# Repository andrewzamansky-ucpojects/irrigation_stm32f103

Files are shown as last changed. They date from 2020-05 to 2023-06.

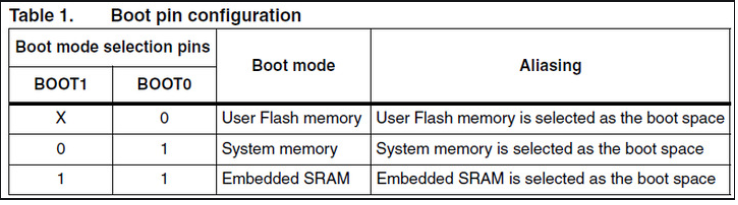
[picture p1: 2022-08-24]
BOOT0_BOOT1_configuration.png

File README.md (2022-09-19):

adc sample of stm32f10x

for using semihost with jlink read "common_public/c/hw_drivers/arch/ARM/semihosting/connect_jlink_with_semihosting.txt"

Debugging:
uncomment following line in main.c(in measurements_thread_func())
before entering hibernation:
//while(1){os_delay_ms(1000);} // to remove, for dbg only

to start JLINK:
for SW thar runs from flash: set BOOT0 and BOOT1 to 1
"C:\Program Files (x86)\SEGGER\JLink\JLink.exe" -device STM32F103C8 -if SWD -speed 4000

to connect to CPU in JLINK cmd line run:
connect

some times board needs to be reset(button) few times before it can connect.

to connect jlink gdb server run:
"C:\Program Files (x86)\SEGGER\JLink\JLinkgdbserver.exe" -device STM32F103C8 -if SWD -speed 4000

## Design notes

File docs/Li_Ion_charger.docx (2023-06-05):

For Li-Ion charger TP4056 chip is used.

To allow simultaneous charging and loading pMOSFET and Schottky Diode are used.

The base of solution was taken from https://www.best-microcontroller-projects.com/tp4056-page2.html

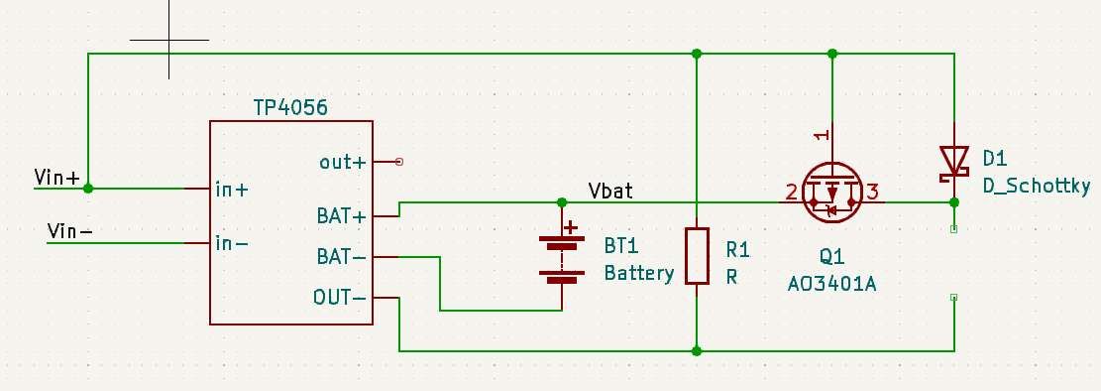
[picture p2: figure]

Vg = Vin

If Vin > 4V then tp4056 will work and charge BT1 battery. Battery charge is from 2.7V to 4.2V so

So Vgs = Vg-(Vb - 0.4V) is more than 0.2V (for highest 4.2V of battery). So Q1 is off. So load is powered by Vin.

If Vin < 4V then tp4056 is not charging the battery. But only when Vgs will be less then -0.55V(typically) then

Q1 will turn on and battery will power the load. So typically Vb-Vg will be > 0.15V.

Note 1: some times on charger board 03962A both red(charging) and blue(standby) LEDs are ‘on’. (while it’s expected that only one of them is ‘on’). I assume that it’s because of high wire resistance the voltage on battery is less than 4.2V, so battery is not fully charge, so when tp4056 stops charging, I is dropped, so IR(voltage) on wires drops, so

More voltage falls on battery so it can pull more current for charging. So tp4056 start charging again. But then it returns to previous condition with higher IR on wires. So it’s toggling between these 2 states causing 2 LEDs to blink very fast, and it looks like they are always ‘on’.

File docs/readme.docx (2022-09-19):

adc sample of stm32f10x

for using semihost with jlink read "common_public/c/hw_drivers/arch/ARM/semihosting/connect_jlink_with_semihosting.txt"

Debugging:

uncomment following line in main.c(in measurements_thread_func())

before entering hibernation:

//while(1){os_delay_ms(1000);} // to remove, for dbg only

1. debugging with J-link

! Cloned J-link are not stable, disconnect after 5-10sec. Better to use Mini Edu official J-link!

to test JLINK:

for SW thar runs from flash: set BOOT0 and BOOT1 to 1

"C:\Program Files (x86)\SEGGER\JLink\JLink.exe" -device STM32F103C8 -if SWD -speed 4000

to connect to CPU in JLINK cmd line run:

connect

some times board needs to be reset(button) few times before it can connect.

to connect jlink gdb server run:

"C:\Program Files (x86)\SEGGER\JLink\JLinkgdbserver.exe" -device STM32F103C8 -if SWD -speed 4000

to connect from eclipse.

a) install GDB SEGGER J-Link debugger

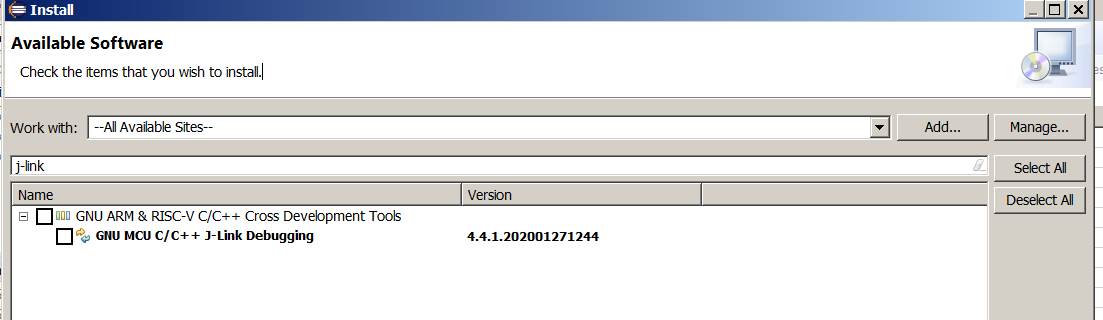
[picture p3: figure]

b) make sure to disable auto build

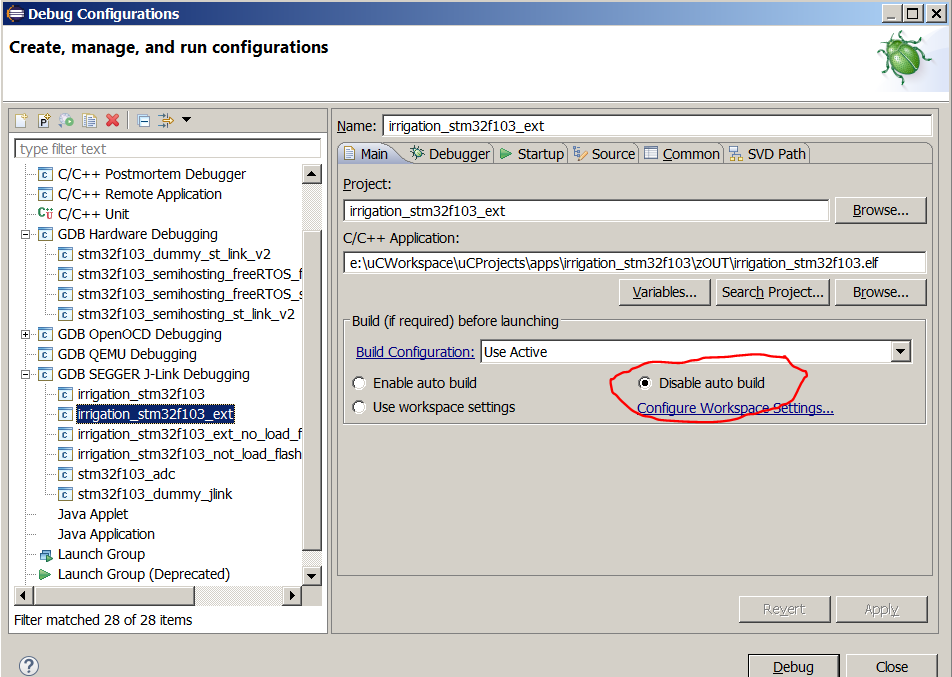
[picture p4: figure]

c) make sure to use the same gdb version as compiler version

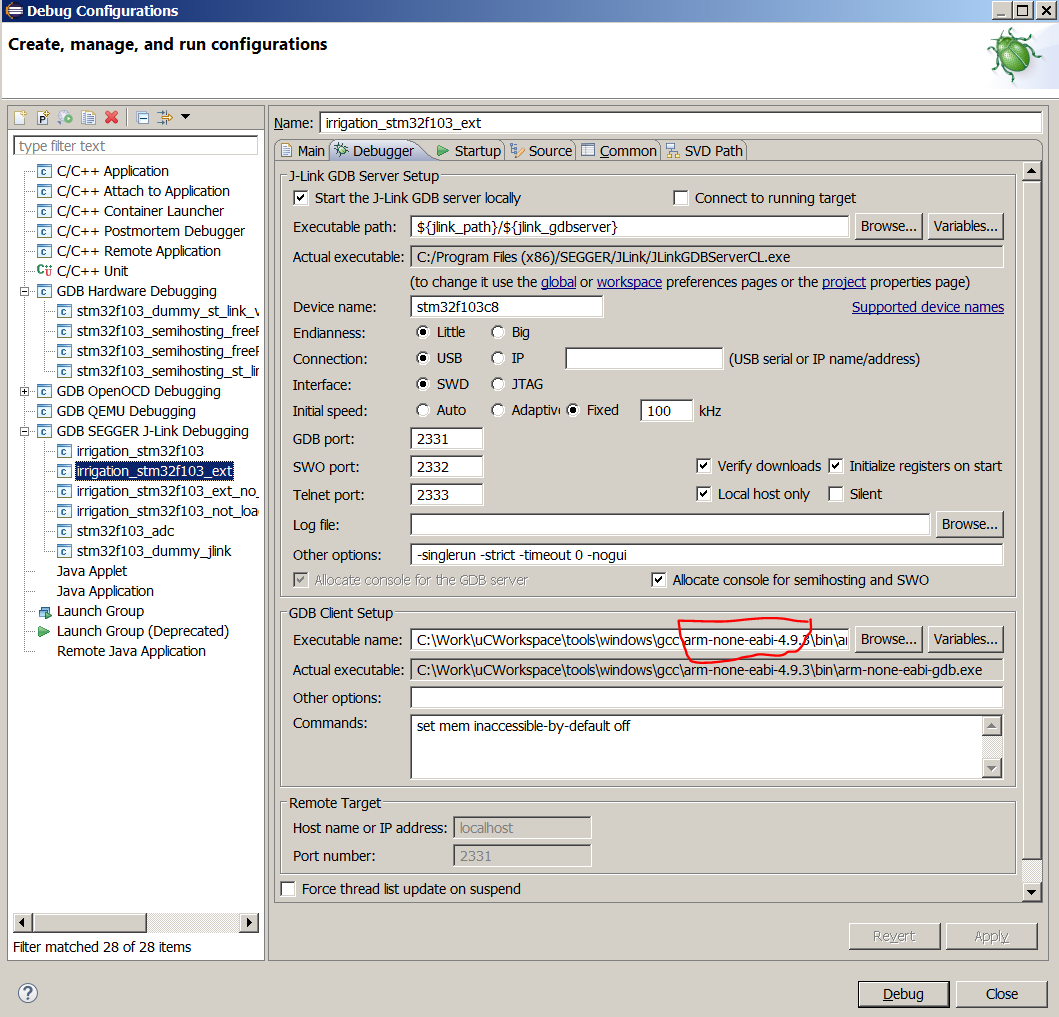
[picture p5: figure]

d)

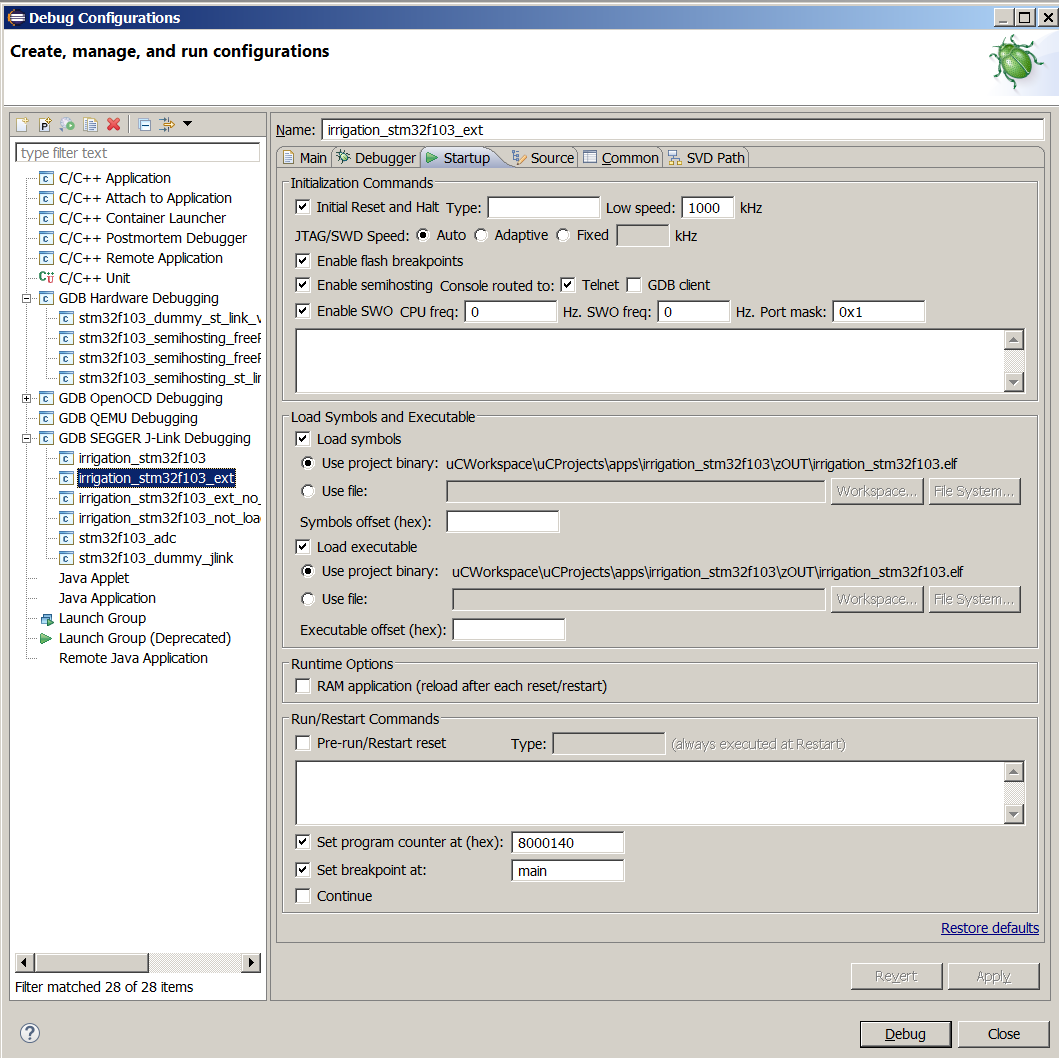
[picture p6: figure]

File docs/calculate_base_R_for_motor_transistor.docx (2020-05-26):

## calculation based on below discussion, but for ST32f1XX, output pin voltage changed to 3.3V.

pin of st32f1xxx can deliver 20mA.

we want Ib at least 5mA. so let’s take 10mA.

R = (3.3V – 1.5V)/10mA = 180Ohm

now using 200Ohm

## taken from: https://teachmetomake.wordpress.com/how-to-use-a-transistor-as-a-switch/

## How to Use A Transistor as a Switch

How to use a transistor a switch (work in progress)

1. Let’s assume you want to switch a motor or a light bulb. The first step is to determine the voltage and current of the load, the thing you are trying to control.

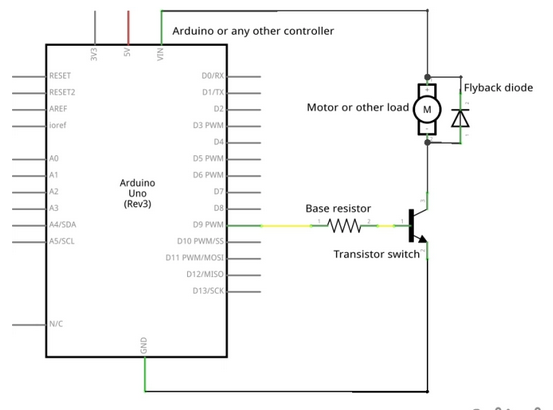
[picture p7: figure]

In the case of the motor, if you know where it came from, you can look up the specifications on the manufacturers website. If you don’t know where it came from, you might have to take a guess or make some measurements.

For a light bulb, the voltage and wattage is usually printed on the bulb. To calculate the current, simply divide the wattage by the voltage. For example, a 12VDC light bulb rated at 24 Watts draws 24W/12V = 2 Amps.

In summary:

1. Can your transistor handle the load current through its collector?
2. Can the transistor handle the supply voltage?
3. Find the worst case current gain during saturation.
4. Calculate the minimum base current needed to keep the transistor in saturation, using this worst case current gain and the load current
5. Compare this base current to the maximum current your microcontroller (or other controlling circuit) can deliver.
6. Find the very highest (worst case) Vbe.
7. Calculate the voltage drop across the base resistor using Vbe and the controller output voltage.
8. Calculate the required base resistor.
9. Calculate the collector power dissipation

Example 1

Jameco 400995 DC gear motor. According to the datasheet for this motor (http://art511.files.wordpress.com/2010/03/solarboticsmotor.pdf), at 12VDC with no load it only draws 76 mA, but if you stall the motor it shoots up to 1250 mA, or 1.25 Amps. A motor always consumes the maximum current when stalled.

Thus the load voltage is 12VDC and the maximum load current is 1.25 A

Vload = 12V
Iload(max) = 1.25A

In general, we can use both PNP or NPN transistors as switches. However, PNP transistors can only control the same voltage as is supplied to the Arduino chip. In this case, since the voltage we are controlling (12 V) is different from the Arduino voltage (5 V), we have no choice but to use an NPN transistor.

Next, we see what NPN transistors we have in our box of parts. Let’s pretend we have a PN2222A, a TIP31 and a TIP120.

Next, we need to check the datasheet for each transistor.

First we need to make sure that the transistor can safely handle the worst current we might draw. The parameter we are looking for is the maximum collector current, Ic(max).

The datasheet for the PN2222A (http://art511.files.wordpress.com/2010/03/2n2222a_to-18.pdf) shows Ic(max) = 0.6 A, which is too little for our needs.

The datasheet for the TIP31 (http://art511.files.wordpress.com/2010/03/tip31.pdf) shows Ic(max) = 3 A, which is safely above the 1.25 A our motor will draw if it is stalled. So the TIP31 is a contender.

Next we have to verify that the transistor can safely handle the supply voltage we plan to use. The parameter we are looking for is the maximum collector emitter voltage, Vceo(max).

The TIP31 comes in 4 versions, with Vceo(max) ranging from 40 V to 100 V, all safely above the 12 V we plan to use. So the TIP31 is still a contender.

Now we need to calculate whether we can provide sufficient base current to keep the transistor in saturation. First we need to find what the base current will be when the transistor is carrying the worst-case current of 1.25 A. According to Figure 2, Ic/Ib = 10 or Ic = 10 * Ib. This means that for our collector current of 1.25 A, we would need to deliver a base current of .125 A, which is too much for our Arduino, which can deliver (safely) at most 40 mA.

Finally let’s take a look at the datasheet for the TIP120 (http://art511.files.wordpress.com/2010/03/tip120.pdf). First, we see that Ic(max) = 5 A, and that Vceo(max) is 60, 80, or 100 V, so we are fine so far.

Next we check the base current. Again this is indicated in Figure 2, but this time Ic=250 * Ib or our collector current of 1.25 A requires a base current of 5 mA (5 * 250 = 1250), which is well below the maximum of 40 mA the Arduino can put out.

Finally we need to select a base resistor which will be low enough to ensure that the TIP120 remains saturated, but high enough to prevent the Arduino from trying to deliver more current than it should. We want a current between 5 mA and 40 mA, so let’s pick a midway point of 20 mA.

Back to Figure 2 where we see that when the collector current is 1 A, Vbe(sat) is about 1.5 V. Now if the Arduino is putting out 5 V, and Vbe is 1.5 V, that means that the resistor has a voltage drop of (5 – 1.5) or 3.5 V across it. Using Ohm’s law, R = V/I = 3.5/(20 mA)= 175 Ohms.

Example 2

This example is from an excellent discussion here. (http://electronics.stackexchange.com/questions/80437/using-a-microcontroller-to-turn-on-led-strip/80443) To summarize: A strip of LEDs requires 400 mA at 12 volts, and is to be controlled from a Raspberry Pi.

A TIP120 (http://art511.files.wordpress.com/2010/03/tip120.pdf) is proposed.

1. Can the TIP120 handle the load current? According to the first page of the datasheet, in the table titled “Absolute Maximum Ratings”, the maximum collector current Ic is 5A, well above our requirements.
2. Can the transistor handle the 12V required? According to the same table as above, Vceo(max) is 60V, well more than we need.
3. Find the worst case current gain during saturation. Note that on page 2 of the datasheet, the DC current gain hfe is quoted at 1000 minimum, but this is at Vce=3V, which is not saturated, so we can’t use that value. Instead, look at Figure 2 on page 3. In the top right corner of this graph is Ic = 250 Ib, so let’s use that value. This seems much higher than the worst case default we use of 10, but given this is a Darlington pair (2 transistors, one after the other), it’s not unreasonable.
4. Calculate the minimum base current needed to keep the transistor in saturation, using this worst case current gain: Ib = Ic/250 = 400 mA / 250 = 1.6 mA.
5. Compare to the maximum current an output of the Raspberry Pi can deliver. There is some confusion over this, but as discussed on this (http://electronics.stackexchange.com/questions/80437/using-a-microcontroller-to-turn-on-led-strip/80443) page 1.6mA seems safe.
6. Find Vbe. According to the graph in Figure 2, Vbe(sat) is below 1.5V all the way up to 1A, so by choosing a worst case Vbe(sat) of 1.5V we should be extremely safe.
7. Now we calculate the voltage drop across the base resistor. The output voltage of the Raspberry Pi is 3.3V, so the voltage drop across the resistor is 3.3V – 1.5V = 1.8V
8. Now we calculate the base resistor. Recall that the minimum base current we need to drive the transistor into saturation is 1.6 mA so R = V / I = 1.8V/1.6mA =~ 1.2K ohm
9. Finally, we should calculate the collector power dissipation, because it’s worse for a Darlington due to the higher Vce(sat). Using Figure 2 again, we see that Vce(sat) is about .75V, so the collector power dissipated is: Pc(max) = Ic(max) * Vce(sat)(max) = 400mA * .75V = 0.3 W. According to the “Absolute Maximum Ratings” table on page 1, the maximum power dissipation is 2W when the ambient temperature Ta = 25C, so we should be safe here as well. .

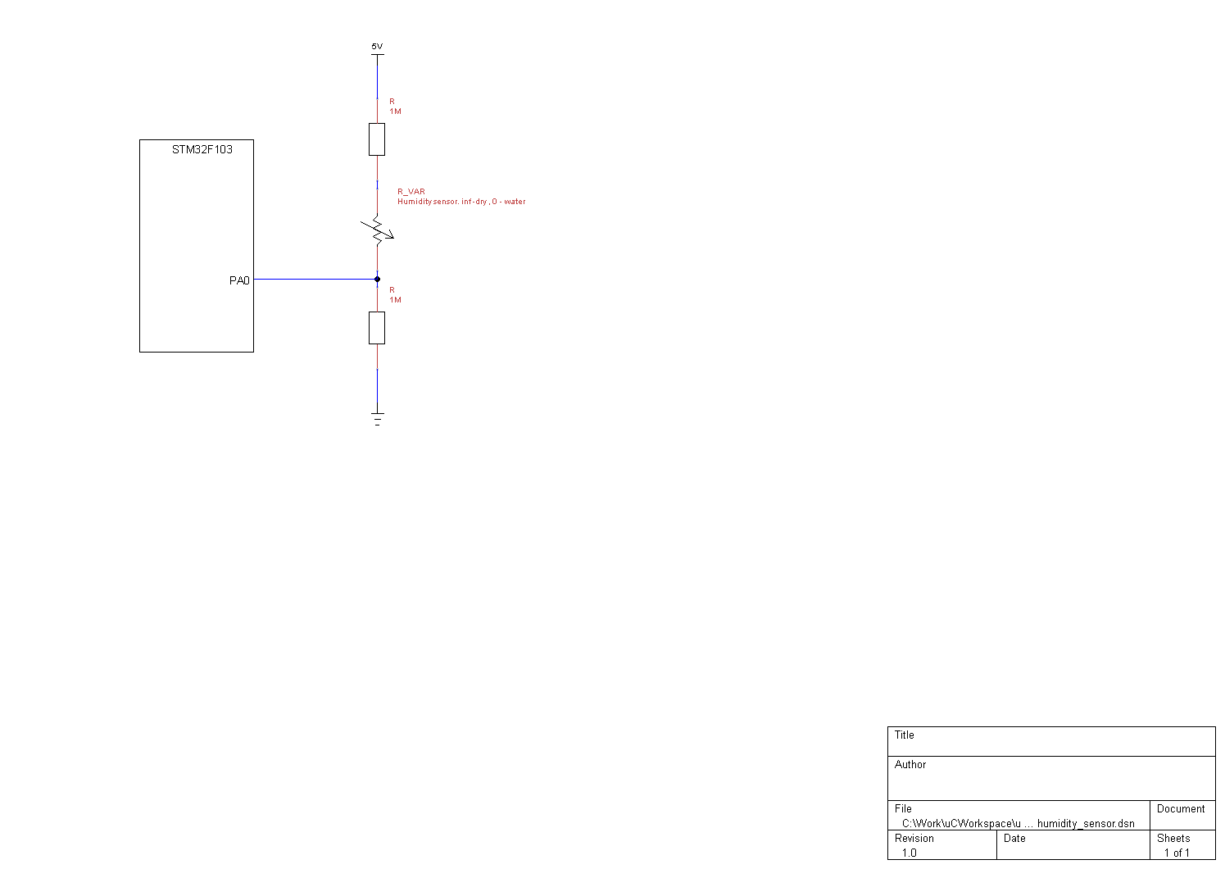
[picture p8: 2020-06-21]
humidity_sensor.png

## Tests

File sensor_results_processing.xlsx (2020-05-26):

2020/05/07 | 13:00:00 |  |  |  | 0 |  | a= | 0.9
 |  |  | remove ‘V’
1 |  | 0.090V | 0.090 | 0.09 |  | <- adding water
2 |  | 0.066V | 0.066 | 0.0876 |  |  |  |  | 0 | 2.852327902
3 |  | 0.000V | 0.000 | 0.07884 |  |  |  |  | 19 | 2.525498104
4 |  | 0.017V | 0.017 | 0.072656 |  |  |  |  | 23 | 2.486760294
5 |  | 0.011V | 0.011 | 0.0664904 |  |  |  |  | 31 | 2.339386051
6 |  | 0.068V | 0.068 | 0.06664136 |  |  |  |  | 44 | 2.375296873
7 |  | 0.051V | 0.051 | 0.065077224 |  |  |  |  | 52 | 2.373131711
8 |  | 0.020V | 0.020 | 0.0605695016 |  |  |  |  | 55 | 2.430247036
9 |  | 0.036V | 0.036 | 0.05811255144 |  |  |  |  | 68 | 2.24903292
10 |  | 0.000V | 0.000 | 0.0523012963 |  |  |  |  | 76 | 2.107072711
11 |  | 0.088V | 0.088 | 0.05587116667 |  |  |  |  | 92 | 1.69902841
12 |  | 0.049V | 0.049 | 0.05518405 |  |  |  |  | 103 | 0.2714114538
13 |  | 0.006V | 0.006 | 0.050265645 |  |  |  |  | 116 | 0.02343918431
14 |  | 0.069V | 0.069 | 0.0521390805
15 |  | 0.006V | 0.006 | 0.04752517245
16 |  | 0.000V | 0.000 | 0.0427726552
17 |  | 0.003V | 0.003 | 0.03879538968
18 |  | 0.012V | 0.012 | 0.03611585072
19 |  | 0.000V | 0.000 | 0.03250426564
20 |  | 0.000V | 0.000 | 0.02925383908
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

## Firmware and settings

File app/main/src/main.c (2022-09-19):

/*
 *
 *   file  :  main.cpp
 *
 */
#include "_project_typedefs.h"
#include "_project_defines.h"
#include "_project_func_declarations.h"
#include "_project_tasks_defines.h"

#include "dev_management_api.h"

#include "os_wrapper.h"
#include "adc_api.h"
#include "gpio_api.h"
#include "rtc_api.h"
#include "pwm_api.h"
#include "pwr_management_api.h"

#define DEBUG
#include "PRINTF_api.h"


extern struct dev_desc_t * adc_humidity_dev;
extern struct dev_desc_t * adc_battery_dev;
extern struct dev_desc_t * motor_control_pin_dev;
extern struct dev_desc_t * blink_led_dev;
extern struct dev_desc_t * pwr_dev;
extern struct dev_desc_t * rtc_dev;
extern struct dev_desc_t * pwm_dev;


// alpha = 0.1  = 1/10 ;   (1 - alpha) = 0.9
#define SMOOTH_ALPHA_NUMERATOR    1
#define SMOOTH_ALPHA_DENOMERATOR  10
#define SMOOTH_ALPHA_DENOMERATOR_MINUS_NUMERATOR  \
				(SMOOTH_ALPHA_DENOMERATOR - SMOOTH_ALPHA_NUMERATOR)

//#define TEST_MEASUREMENTS
#if defined(TEST_MEASUREMENTS)
	#define NUM_OF_MEASUREMENTS   0xffffff // 10
	#define DELAY_BETWEEN_ADC_SAMPLES_mSEC   2000
#else
	#define NUM_OF_MEASUREMENTS   100 // 10
	#define DELAY_BETWEEN_ADC_SAMPLES_mSEC   2
#endif

static uint8_t rtc_calibration_done = 0;

#define MOISTURE_LOW_THRESHOLD_mV  2250//2100

// measures on voltage divider resistor with ~1/10 ratio so threshold = 4750mV
#define BATTERY_THRESHOLD_mV  475

#define STATUS_OK_DELAY 1000
#define STATUS_LOW_BATTERY_DELAY 100

#define STANDBY_NORMAL_TIME  (12 * 60 * 60 * 1000) // 12hours

// small standby time to increase chances that blinks or beeps will
// be noticed by human
#define STANDBY_LOW_BATTERY_TIME  (30 * 1000) // 30 seconds


static void report_status(
		uint32_t blink_beep_delay_ms, uint8_t times_to_blink_or_beep)
{
	uint8_t blink_beep_state;
	uint8_t i;

	blink_beep_state = 1;
	for (i = 0; i < (times_to_blink_or_beep * 2); i++)
	{
		if (blink_beep_state)
		{
			DEV_IOCTL(blink_led_dev, IOCTL_GPIO_PIN_CLEAR );
			DEV_IOCTL(pwm_dev, IOCTL_PWM_ENABLE_OUTPUT);
		}
		else
		{
			DEV_IOCTL(blink_led_dev, IOCTL_GPIO_PIN_SET );
			DEV_IOCTL(pwm_dev, IOCTL_PWM_DISABLE_OUTPUT);
		}
		blink_beep_state = 1 - blink_beep_state;


		os_delay_ms(blink_beep_delay_ms);
	}

}


/**
 * init_hw()
 *
 * return:
 */
static void init_hw(void)
{
	struct dev_desc_t * dev;
	struct set_pwm_params pwm_params;

	DEV_IOCTL(blink_led_dev, IOCTL_DEVICE_START);

	dev = DEV_OPEN("semihosting_dev");
	if (NULL != dev)
	{
		DEV_IOCTL(dev, IOCTL_DEVICE_START);
		PRINTF_API_AddDebugOutput(dev);
	}

	DEV_IOCTL(adc_humidity_dev, IOCTL_DEVICE_START);
	DEV_IOCTL(adc_battery_dev, IOCTL_DEVICE_START);
	DEV_IOCTL(motor_control_pin_dev, IOCTL_DEVICE_START);
	DEV_IOCTL(motor_control_pin_dev, IOCTL_GPIO_PIN_CLEAR );

	DEV_IOCTL(pwm_dev, IOCTL_DEVICE_START);
	pwm_params.freq = 2000;
	pwm_params.duty_cycle_mPercent = 50000;
	DEV_IOCTL(pwm_dev, IOCTL_PWM_SET_PARAMS, &pwm_params);
//	while (1) // just for speaker test
//	{
//		report_status(500, 3);
//		os_delay_ms(5000);
//	}

}


/**
 * make_measurements()
 *
 * return:
 */
static void make_measurements(uint32_t *humidity, uint32_t *battery_level)
{
	uint32_t cnt;
	uint32_t adc_humidity_val;
	uint32_t adc_battery_val;
	uint32_t battery_avg_val;
	uint32_t smoothed_adc_humidity_val;

	smoothed_adc_humidity_val = 500;// not relevant for averaging
	battery_avg_val = 0;

	for (cnt = 0; cnt < NUM_OF_MEASUREMENTS; cnt++)
	{
		DEV_IOCTL(adc_battery_dev,
				IOCTL_ADC_GET_CURRENT_VALUE_mV, &adc_battery_val);
		PRINTF_DBG("%05d  bat = %d.%03dV; ",
				cnt, adc_battery_val / 1000, adc_battery_val % 1000);

		battery_avg_val *= (cnt - 1);
		battery_avg_val += adc_battery_val;
		battery_avg_val /= cnt;
		PRINTF_DBG("bat_avg = %d.%03dV\r\n",
				battery_avg_val / 1000, battery_avg_val % 1000);

		DEV_IOCTL(adc_humidity_dev,
				IOCTL_ADC_GET_CURRENT_VALUE_mV, &adc_humidity_val);
		PRINTF_DBG("%d.%03dV; ",
				adc_humidity_val / 1000, adc_humidity_val % 1000);
#if 0
		// smoothed_adc_humidity_val =
		// (1 - alpha) * smoothed_adc_humidity_val + alpha * adc_humidity_val
		adc_humidity_val *= SMOOTH_ALPHA_NUMERATOR;
		smoothed_adc_humidity_val *= SMOOTH_ALPHA_DENOMERATOR_MINUS_NUMERATOR;
		smoothed_adc_humidity_val += adc_humidity_val;
		smoothed_adc_humidity_val /= SMOOTH_ALPHA_DENOMERATOR;
#else
		smoothed_adc_humidity_val *= (cnt - 1);
		smoothed_adc_humidity_val += adc_humidity_val;
		smoothed_adc_humidity_val /= cnt;
#endif
		PRINTF_DBG("smoothed %d.%03dV\r\n",
			smoothed_adc_humidity_val / 1000, smoothed_adc_humidity_val % 1000);


		while (PRINTF_API_print_from_debug_buffer(64));

		os_delay_ms(DELAY_BETWEEN_ADC_SAMPLES_mSEC);

	}
	*humidity = smoothed_adc_humidity_val;
	*battery_level = battery_avg_val;
}


/**
 * measurements_thread_func()
 *
 * return:
 */
static void measurements_thread_func(void * aHandle)
{
	uint32_t wakeup_val_mSec;
	uint32_t humidity;
	uint32_t battery_level;

	init_hw();
	make_measurements(&humidity, &battery_level);

	if (battery_level < BATTERY_THRESHOLD_mV)
	{
		report_status(STATUS_LOW_BATTERY_DELAY, 3);
		wakeup_val_mSec = STANDBY_LOW_BATTERY_TIME;
	}
	else
	{
		if (MOISTURE_LOW_THRESHOLD_mV > humidity)
		{
			DEV_IOCTL(motor_control_pin_dev, IOCTL_GPIO_PIN_SET );
		}
		os_delay_ms(3000);
		DEV_IOCTL(motor_control_pin_dev, IOCTL_GPIO_PIN_CLEAR );
		wakeup_val_mSec = STANDBY_NORMAL_TIME;
	}

	while (0 == rtc_calibration_done)
	{
		os_delay_ms(50);
	}

	os_stack_test(); //requires PRINTF_DBG
	while (PRINTF_API_print_from_debug_buffer(64));

	while(1){os_delay_ms(1000);} // to remove, for dbg only

	DEV_IOCTL(rtc_dev, IOCTL_RTC_SET_WAKEUP_mSec, &wakeup_val_mSec);
	DEV_IOCTL(pwr_dev, IOCTL_POWER_MANAGEMENT_ENTER_HIBERNATION);
	// should not reach here
	while(1)
	{
		os_delay_ms(1000);
	}

}


/**
 * rtc_calibration_thread_func()
 *
 * do RTC clock calibration for 100ms while other tasks perform measurments
 */
static void rtc_calibration_thread_func(void * aHandle)
{

	DEV_IOCTL(pwr_dev, IOCTL_DEVICE_START);//should be before RTC
	DEV_IOCTL(rtc_dev, IOCTL_DEVICE_START);
	DEV_IOCTL(rtc_dev, IOCTL_RTC_CALIBRATE);

	rtc_calibration_done = 1;
	while(1)
	{
		os_delay_ms(1000);
	}
}


/*
 * function : main()
 *
 */
int main(void)
{
	struct dev_desc_t * dev;

	dev = DEV_OPEN("soc_clock_control_dev");
	if (NULL == dev) goto error;
	DEV_IOCTL(dev , IOCTL_DEVICE_START  );

	dev = DEV_OPEN("systick_dev");
	if (NULL == dev) goto error;
	os_set_tick_timer_dev(dev);
	os_init();

	PRINTF_API_init();

	os_create_task("test_thread", measurements_thread_func, NULL,
				MEASUREMENTS_THREAD_STACK_SIZE_BYTES,
				MEASUREMENTS_THREAD_PRIORITY);
	os_create_task("test_thread", rtc_calibration_thread_func, NULL,
		RTC_CALIBRATION_THREAD_STACK_SIZE_BYTES,
		RTC_CALIBRATION_THREAD_PRIORITY);

	os_start();

	while(1);
error :
	while(1);
}

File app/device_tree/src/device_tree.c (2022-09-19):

#include "_project.h"

#include "dev_management_api.h"
#include "dt_pin_control_stm32f10x.h"


/***********************************/
/********** soc_clock_control_dev ********/
#define DT_DEV_NAME                        soc_clock_control_dev
#define DT_DEV_MODULE                      clock_control_stm32f10x

#define CLOCK_CONTROL_STM32f10X_DT_HIRC_RATE           8000000
#define CLOCK_CONTROL_STM32f10X_DT_LIRC_RATE           40000
//#define CLOCK_CONTROL_STM32f10X_DT_XTAL_RATE           8000000
#define CLOCK_CONTROL_STM32f10X_DT_SYSCLK_SRC_CLK_DEV    stm32f10x_hsirc_clk_dev//stm32f10x_hsirc_clk_dev//stm32f10x_xtal_clk_dev
//#define CLOCK_CONTROL_STM32f10X_DT_PLL_SRC_CLK_DEV     stm32f10x_hsirc_clk_dev//stm32f10x_xtal_clk_dev
//#define CLOCK_CONTROL_STM32f10X_DT_PLL_RATE        72000000
#define CLOCK_CONTROL_STM32f10X_DT_HCLK_RATE       8000000//72000000
#define CLOCK_CONTROL_STM32f10X_DT_APB1_RATE          8000000
#define CLOCK_CONTROL_STM32f10X_DT_APB2_RATE          8000000

#include ADD_CURRENT_DEV




/***********************************/
/********** systick_dev ********/
#define DT_DEV_NAME                        systick_dev
#define DT_DEV_MODULE                      cortexM_systick

#define CORTEXM_SYSTICK_DT_CLOCK_PDEV      stm32f10x_systick_clk_dev
#define CORTEXM_SYSTICK_DT_INITIAL_RATE    OS_TICK_IN_MICRO_SEC
#define CORTEXM_SYSTICK_DT_MODE            TIMER_API_PERIODIC_MODE

#include ADD_CURRENT_DEV




/***********************************/
/********** adc_humidity_dev ********/
#define DT_DEV_NAME                        adc_humidity_dev
#define DT_DEV_MODULE                      adc_stm32f10x

#define ADC_STM32F10X_DT_CLOCK_RATE      4000000
#define ADC_STM32F10X_DT_INPUT_PIN     PIN_CONTROL_DT_STM32F10X_PIN_A00_ADC

#include ADD_CURRENT_DEV



/***********************************/
/********** adc_battery_dev ********/
#define DT_DEV_NAME                        adc_battery_dev
#define DT_DEV_MODULE                      adc_stm32f10x

#define ADC_STM32F10X_DT_CLOCK_RATE      4000000
#define ADC_STM32F10X_DT_INPUT_PIN     PIN_CONTROL_DT_STM32F10X_PIN_A02_ADC

#include ADD_CURRENT_DEV




/***********************************/
/********** rtc_dev ********/
#define DT_DEV_NAME                        rtc_dev
#define DT_DEV_MODULE                      rtc_stm32f10x

#define RTC_STM32F10X_DT_SRC_CLOCK_DEV      stm32f10x_lsirc_clk_dev
#define RTC_STM32F10X_DT_COUNTER_RATE_HZ    1//625

#include ADD_CURRENT_DEV




/***********************************/
/********** pwr_dev ********/
#define DT_DEV_NAME                        pwr_dev
#define DT_DEV_MODULE                      pwr_stm32f10x

#include ADD_CURRENT_DEV




/***********************************/
/********** semihosting_dev ********/
#define DT_DEV_NAME                      semihosting_dev
#define DT_DEV_MODULE                    semihosting

#include ADD_CURRENT_DEV


/***********************************/
/********** motor_control_pin_dev  ********/
#define DT_DEV_NAME                      motor_control_pin_dev
#define DT_DEV_MODULE                    gpio_stm32f10x

#define GPIO_STM32F10X_DT_PORT         GPIO_STM32F10X_API_PORT_A
#define GPIO_STM32F10X_DT_PINS             {1}
#define GPIO_STM32F10X_DT_PINS_IDLE_STATE  {0}
#define GPIO_STM32F10X_DT_MODE         GPIO_STM32F10X_API_MODE_OUT_PP

#include ADD_CURRENT_DEV


/***********************************/
/********** blink_led_dev  ********/
#define DT_DEV_NAME                      blink_led_dev
#define DT_DEV_MODULE                    gpio_stm32f10x

#define GPIO_STM32F10X_DT_PORT         GPIO_STM32F10X_API_PORT_C
#define GPIO_STM32F10X_DT_PINS             {13}
#define GPIO_STM32F10X_DT_PINS_IDLE_STATE  {0}
#define GPIO_STM32F10X_DT_MODE         GPIO_STM32F10X_API_MODE_OUT_PP

#include ADD_CURRENT_DEV


/***********************************/
/********** pwm_dev  ********/
#define DT_DEV_NAME                      pwm_dev
#define DT_DEV_MODULE                    pwm_stm32f10x

#define PWM_STM32F10X_DT_OUTPUT_PIN     PIN_CONTROL_DT_STM32F10X_PIN_A08_PWM

#include ADD_CURRENT_DEV

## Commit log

2020-02-03 add control pin
2020-05-05 add circuit for sensor
2020-05-26 add motor pin and hibernation mode
    [sensor_results_processing.xlsx]
2020-06-21 split code to several functions
    [humidity_sensor.dsn]
2020-06-24 add PWM
2022-08-24 up-merge with latest common_public
    [humidity_sensor.dsn]
2022-09-19 add adc measurements
2023-06-05 update documentation
    [irrigation_stm32f103.kicad_pcb, irrigation_stm32f103.kicad_sch]
